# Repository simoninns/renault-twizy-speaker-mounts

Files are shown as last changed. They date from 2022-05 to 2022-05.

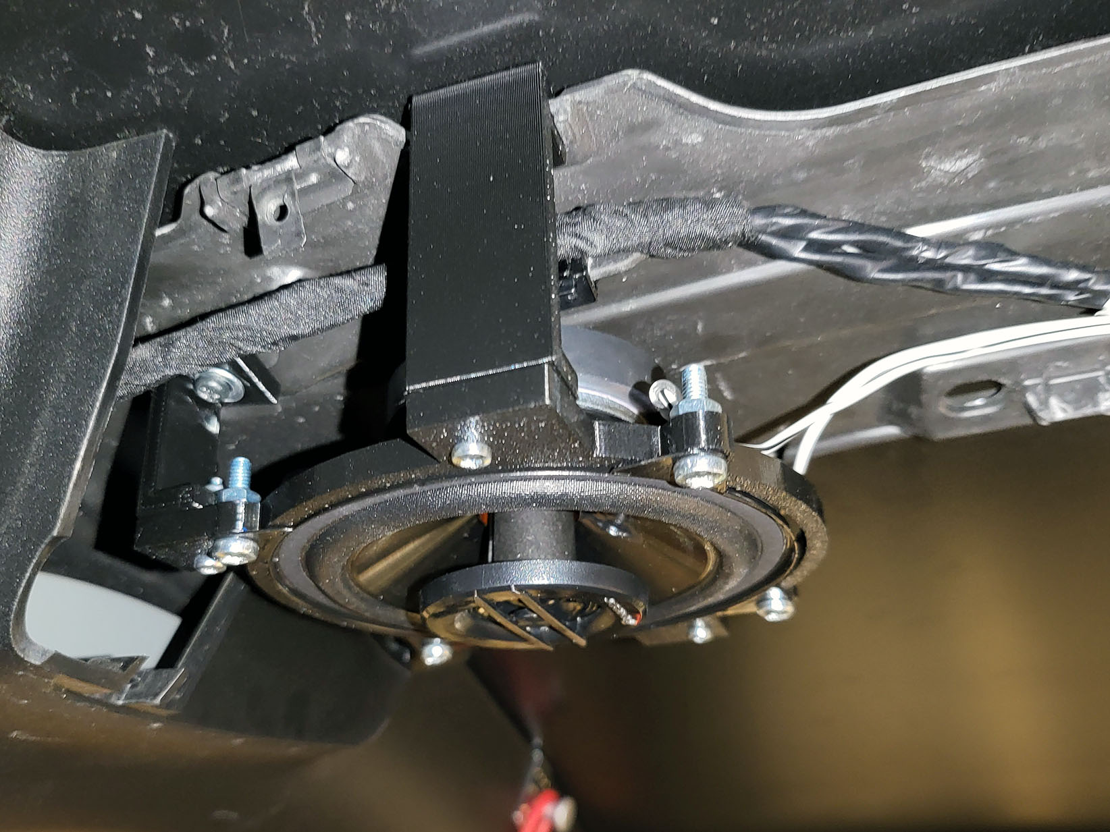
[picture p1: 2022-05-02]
images/20220502_142706.jpg

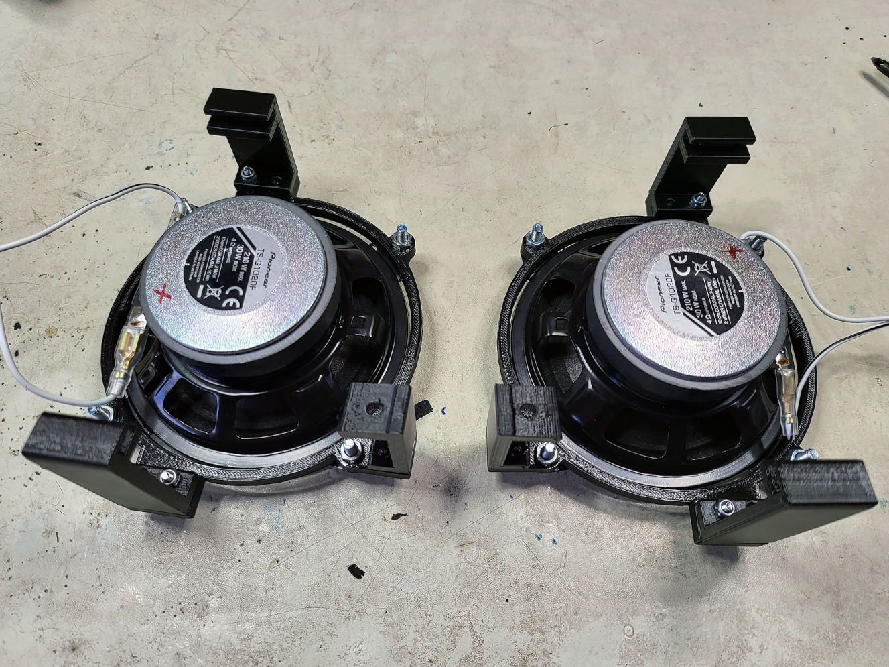
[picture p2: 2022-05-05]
images/20220502_124944.jpg

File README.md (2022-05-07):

# Renault Twizy Speaker Mounts
## Overview
This project provides a set of speaker mounts for the Renault Twizy.  The mounts are designed to fit 4 inch speakers with 45 degree 170-172mm mounts and are mounted in the original bracket position in the roof of the car.

Tested speakers include:

* Pioneer TS-G1020F (good value)
* Alpine SPG-10C2 (best performance)

This project is open-source.  You can find the OpenSCAD source here: https://github.com/simoninns/renault-twizy-speaker-mounts

## Printing instructions
The model has been printed and tested on the Prusa MK3S/MMU2S printer using Prusament PETG filament. All parts fit on a 20x20 printing bed.

### Recommended print settings

Print settings (for Prusa Slicer) are the same for all included parts:

* Material: PETG
* Layer: 0.30mm
* Infill: 25%
* Supports: No Supports

# Assembly
Since the bracket will need to withstand vibration, ensure that you use either nylon lock-nuts or thread-lock for all screws.

The clips are attached to the bracket using M3x16mm screws.  The speaker is attached using 4xM4 screws.  The screw-heads should be on the underside of the bracket.

Note that the two clip-on arms of the bracket have recesses for the Twizy's mounting point - these 'click' into place and should be firmly pressed into the car's mounting points.

See the included pictures for more details.

Note that the screw-clip has a different orientation on the left and right brackets.

## Author
This project is designed and maintained by Simon Inns.

# Licensing
## OpenSCAD source files - software license (GPLv3)

    This is free software: you can redistribute it and/or modify
    it under the terms of the GNU General Public License as published by
    the Free Software Foundation, either version 3 of the License, or
    (at your option) any later version.
    
    This program is distributed in the hope that it will be useful,
    but WITHOUT ANY WARRANTY; without even the implied warranty of
    MERCHANTABILITY or FITNESS FOR A PARTICULAR PURPOSE.  See the
    GNU General Public License for more details.
    
    You should have received a copy of the GNU General Public License
    along with this program.  If not, see <http://www.gnu.org/licenses/>.

## Non-source-code media - Creative Commons license (Creative Commons BY-SA 4.0)
Please see the following link for details: https://creativecommons.org/licenses/by-sa/4.0/

You are free to:

Share - copy and redistribute the material in any medium or format
Adapt - remix, transform, and build upon the material
for any purpose, even commercially.

This license is acceptable for Free Cultural Works.

The licensor cannot revoke these freedoms as long as you follow the license terms.

Under the following terms:

Attribution - You must give appropriate credit, provide a link to the license, and indicate if changes were made. You may do so in any reasonable manner, but not in any way that suggests the licensor endorses you or your use.

ShareAlike - If you remix, transform, or build upon the material, you must distribute your contributions under the same license as the original.

No additional restrictions - You may not apply legal terms or technological measures that legally restrict others from doing anything the license permits.

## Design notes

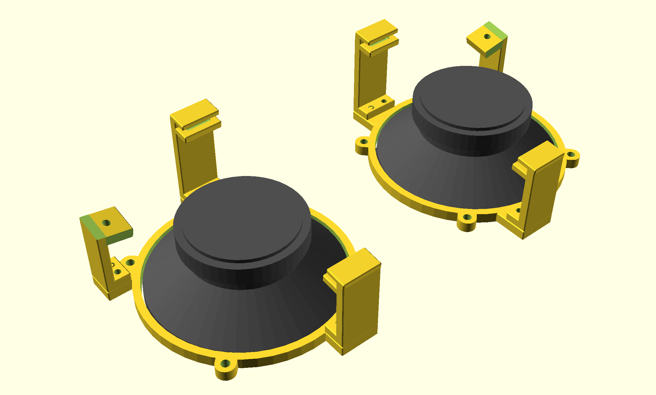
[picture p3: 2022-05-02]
images/openscad_render.png

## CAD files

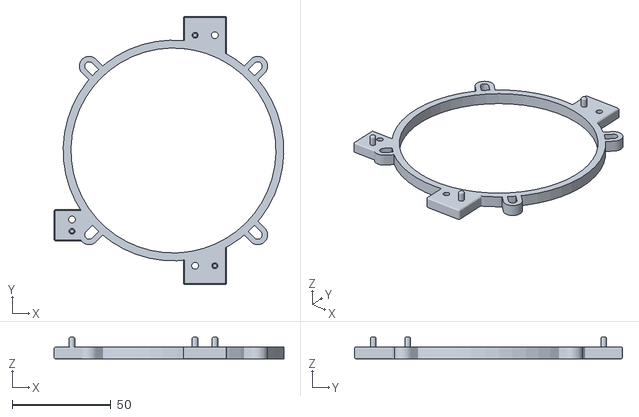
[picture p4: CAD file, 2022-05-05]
stl/left_mount.stl
116.5 x 136.0 x 11.0

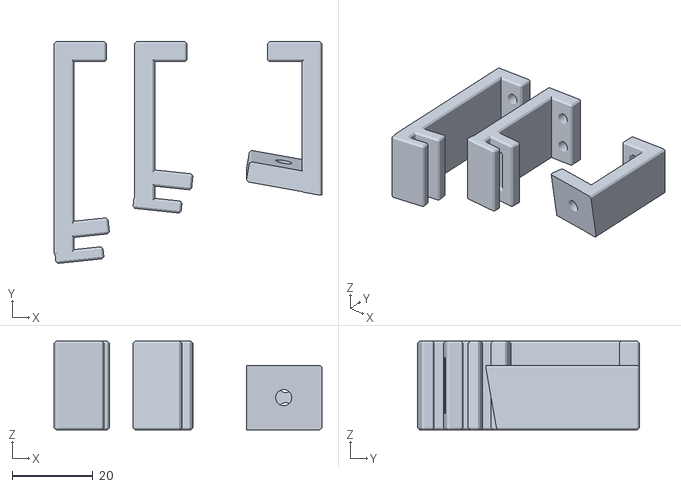
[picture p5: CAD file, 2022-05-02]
stl/left_clips.stl
66.5 x 55.1 x 22.0

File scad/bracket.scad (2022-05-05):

/************************************************************************

    bracket.scad
    
    Renault Twizy Speaker Mounts
    Copyright (C) 2022 Simon Inns
    
    This is free software: you can redistribute it and/or modify
    it under the terms of the GNU General Public License as published by
    the Free Software Foundation, either version 3 of the License, or
    (at your option) any later version.
    
    This program is distributed in the hope that it will be useful,
    but WITHOUT ANY WARRANTY; without even the implied warranty of
    MERCHANTABILITY or FITNESS FOR A PARTICULAR PURPOSE.  See the
    GNU General Public License for more details.
    
    You should have received a copy of the GNU General Public License
    along with this program.  If not, see <http://www.gnu.org/licenses/>.
	
    Email: simon.inns@gmail.com
    
************************************************************************/

include <BOSL/constants.scad>
use <BOSL/transforms.scad>
use <BOSL/shapes.scad>

module bracket_catch_top()
{
    move([0,0,3]) cuboid([22,12,3], chamfer=0.5); // Over the Top

    difference() {
        move([0,2,-3.5]) cuboid([22,12,4], chamfer=0.5); // underneath
        move([0,2.5,-2]) cuboid([14,3,2], chamfer=0.5);
    }
}

module bracket_mounting_holes()
{
    move([0,0,-2]) {
        difference() {
            union() {
                hull() {
                    move([0,+(117/2) + 2,0]) cyl(h=6,d=10);
                    move([0,-(117/2) - 2,0]) cyl(h=6,d=10);
                }
                hull() {
                    move([+(117/2) + 2,0,0]) cyl(h=6,d=10);
                    move([-(117/2) - 2,0,0]) cyl(h=6,d=10);
                }
            }

            hull() {
                move([0,+(117/2) - 2,0]) cyl(h=10,d=4.5);
                move([0,+(117/2) + 2,0]) cyl(h=10,d=4.5);
            }

            hull() {
                move([0,-(117/2) + 2,0]) cyl(h=10,d=4.5);
                move([0,-(117/2) - 2,0]) cyl(h=10,d=4.5);
            }

            hull() {
                move([+(117/2) + 2,0,0]) cyl(h=10,d=4.5);
                move([+(117/2) - 2,0,0]) cyl(h=10,d=4.5);
            }

            hull() {
                move([-(117/2) + 2,0,0]) cyl(h=10,d=4.5);
                move([-(117/2) - 2,0,0]) cyl(h=10,d=4.5);
            }
        }
    }
}

module bracket_speaker_mount()
{
    difference() {
        union() {
            move([0,0,-2]) cyl(h=6, d=112);
            bracket_mounting_holes();
        }
        move([0,0,-3]) cyl(h=10, d=110-6);
    }
}

module bracket_screw_mount(isRight)
{
    twist = (isRight == true) ? -10:10;
    move([0,-3,0]) {
        // Body screw hole at top of clip
        difference() {
            move([66,-35,-13.5 - 4.25]) xrot(twist) yrot(-10) cuboid([16,20,5], chamfer=0.5);
            move([67,-35,-7 - 8]) cyl(h=40,d=4);

            move([66,-45,-13.5 - 4.25]) cuboid([20,4,30]);
            move([66,-25,-13.5 - 4.25]) cuboid([20,4,30]);
        }
        
        // Main stem
        difference() {
            move([74,-35,-30]) cuboid([5,16,40], chamfer=0.5);
            move([60,-35,-11]) xrot(twist) yrot(-10) cuboid([40,20,10]);
        }

        // Foot
        difference() {
            move([68,-35,-47.5]) cuboid([10,16,5], chamfer=0.5);       
            move([67.5,-32,-48.5]) cyl(h=20,d=3.5); // M3 Screw
            move([67.5,-38,-48.5]) cyl(h=20,d=3.5); // Locator pin
        }  
    }
}

// Long back
module bracket_catch1()
{
    difference() {
        union() {
            move([0,-62,0]) xrot(-6) bracket_catch_top();
            move([0,-65.5,-23.5]) cuboid([22,5,53], chamfer=0.5);
            move([0,-60,-47.5]) cuboid([22,10,5], chamfer=0.5);
            
        }
        move([5,-58.5,-48.5]) cyl(h=20,d=3.5); // M3 Screw
        move([-5,-58.5,-48.5]) cyl(h=20,d=3.5); // Locator pin
        move([4,0,-52.5]) cyl(h=20,d=110);
    }   
}

// Short front
module bracket_catch2()
{
    difference() {
        union() {
            move([0, 62,-12.5]) xrot(-6) zrot(180) bracket_catch_top();
            move([0,65.5,-30]) cuboid([22,5,40], chamfer=0.5);
            move([0,60,-47.5]) cuboid([22,10,5], chamfer=0.5);
        }
        move([-5,58.5,-48.5]) cyl(h=20,d=3.5); // M3 Screw
        move([+5,58.5,-48.5]) cyl(h=20,d=3.5); // Locator pin
        move([4,0,-52.5]) cyl(h=20,d=110);
    }
}

module render_right_clips(toPrint)
{
    // Render the catches
    if (toPrint) {
        move([40,-30,11]) rotate([90,90,0]) bracket_catch1();
        move([60,-30,11]) rotate([90,-90,0]) bracket_catch2();
        move([-38,-30,46]) rotate([90,0,0]) bracket_screw_mount(true);
    } else {
        bracket_catch1();
        bracket_catch2();
        bracket_screw_mount(true);
    }
}

module render_left_clips(toPrint)
{
    // Render the catches
    if (toPrint) {
        move([40,-30,11]) rotate([90,90,0]) bracket_catch1();
        move([60,-30,11]) rotate([90,-90,0]) bracket_catch2();
        move([-38,-30,46]) rotate([90,0,0]) bracket_screw_mount(false);
    } else {
        move([-114,0,0]) {
            move([-8,0,0]) bracket_catch1();
            move([-8,0,0]) bracket_catch2();
        }
        move([-130,0,0]) zrot(180) {
            move([-8,76,0]) bracket_screw_mount(false);
        }
    }
}

module g_mount()
{
    // Speaker support
    move([16,0,-51]) zrot(45) bracket_speaker_mount();

    // Join the catches to the speaker support
    difference() {
        union() {
            move([0,0,-53]) cuboid([22,136,6], chamfer=0.5); // Join the clips
            move([67.5,-38,-53]) cuboid([18,16,6], chamfer=0.5); // Join the screw mount
        }
        
        // Clear the screw hole
        move([16,0,0]) zrot(45) move([0,-(117/2),-50]) {
            hull() {
                move([0, +2,0]) cyl(h=20,d=4.5);
                move([0, -2,0]) cyl(h=20,d=4.5);
            }
        }
        
        move([16,0,-50]) cyl(h=20, d=104);

        // Add screw holes for catches and screw mount
        move([5,-58.5,-48.5]) cyl(h=20,d=3.5); // M3 Screw 1
        move([-5,58.5,-48.5]) cyl(h=20,d=3.5); // M3 Screw 2
        move([67.5,-32 - 3,-48.5]) cyl(h=20,d=3.5); // M3 Screw (screw clip)
    }

    
}

module r_mount()
{
    g_mount();

    // Locator pins
    move([-5,-58.5,-47.5]) cyl(h=5,d=3, chamfer2=0.5); // Locator pin
    move([+5,58.5,-47.5]) cyl(h=5,d=3, chamfer2=0.5); // Locator pin
    move([67.5,-38 - 3,-47.5]) cyl(h=5,d=3, chamfer2=0.5); // Locator pin
}

module l_mount()
{
    yrot(180) move([-8,0,51 * 2 + 4]) {
        g_mount();

        // Locator pins
        move([-5,-58.5,-47.5 - 11]) cyl(h=5,d=3, chamfer1=0.5); // Locator pin
        move([+5,58.5,-47.5 - 11]) cyl(h=5,d=3, chamfer1=0.5); // Locator pin
        move([67.5,-38 - 3,-47.5 -11]) cyl(h=5,d=3, chamfer1=0.5); // Locator pin
    }
}

module render_right_mount(toPrint)
{
    if (toPrint) move([-10,-10,56]) r_mount();
    else r_mount();
}

module render_left_mount(toPrint)
{
    if (toPrint) move([-10,-10,56]) l_mount();
    else move([-130,0,0]) l_mount();
}

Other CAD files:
stl/right_mount.stl
stl/right_clips.stl
scad/main.scad
scad/speaker.scad

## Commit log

2022-05-01 First push of the project files
    [bracket.scad, left_clips.stl, left_mount.stl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]
2022-05-01 Moved speakers over towards the centre to improve clearance
    [bracket.scad, left_clips.stl, left_mount.stl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]
2022-05-01 Updated openSCAD rendering of brackets
2022-05-01 Updated photographs of mounting bracket
2022-05-02 Tilted brackets down to make them fit correctly and updated project files
    [bracket.scad, left_clips.stl, left_mount.stl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]
2022-05-05 Made speaker mount holes elongated to fit a wider range of speakers
    [bracket.scad, left_mount.stl, right_mount.stl]
